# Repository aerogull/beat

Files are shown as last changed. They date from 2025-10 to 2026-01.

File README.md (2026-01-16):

# beat - a mouse designed for any case
I've wanted to design my own mouse for the longest time. I've built my own keyboard, so it was just the next logical step, right? Well, the complexity from a keyboard run off a microcontroller powered by qmk, to a custom programmed mouse with a proprietary mouse sensor and a nRF52 chip, was quite the leap. This is a v1, it's not going to be light, it's not going to be very small, the side button connectors will likely be changed, and the case will not be ergonomic in any way that isn't comfortable to me. The firmware will be slower than most modern mice, and I probably won't be able to bring out the full speed of the PAW3395 sensor used (if I use ESB). But this is a testing board, and changes will be made to improve it in the future! With that, onto the specs and design!
## PCB
- nRF52840
- PAW3395
- 11mm compatible Alps scroll (w middle click)
- 4 Omron Switches (1 other switch for middle click)
- Lipo battery (500mAH)
- Dongle (nRF52840 + USBC) (COMING SOON)
- USBC charging

pcb
schematic1
schematic2
## Case
It's just a simple design without great ergonomics, mostly used for testing and ease of access to the board.
## Firmware
_**Warning: The PAW3395 Driver is Propiretiary, and Can Not Be Provided by Me**_ 

## BOM
|Reference|Qty|Value|DNP|Exclude from BOM|Exclude from Board|Footprint|Datasheet|
|-----|-----|-----|-----|-----|-----|-----|-----|
|A1|1|~||||custom:PAW3395||
|C1,C29,C39|	3|	4.7μF|	|	|	|	Capacitor_SMD:C_0805_2012Metric_Pad1.18x1.45mm_HandSolder|	~|
|C2,C4,C5,C13,C14,C19,C20,C21,C22,C23,C28,C31,C38|	13|	100nF|	|	|	|	Capacitor_SMD:C_0805_2012Metric_Pad1.18x1.45mm_HandSolder|	~|
|C3,C6,C8,C10,C12,C15,C16,C18,C41,C43|	10|	10μF|	|	|	|	Capacitor_SMD:C_0805_2012Metric_Pad1.18x1.45mm_HandSolder|	~|
|C7|	1|	33uF|	|	|	|	Capacitor_SMD:C_0805_2012Metric_Pad1.18x1.45mm_HandSolder|	~|
|C11,C17,C42|	3|	1μF|	|	|	|	Capacitor_SMD:C_0805_2012Metric_Pad1.18x1.45mm_HandSolder|	~|
|C24,C25,C26,C27|	4|	12pF|	|	|	|	Capacitor_SMD:C_0805_2012Metric_Pad1.18x1.45mm_HandSolder|	~|
|C30,C32|	2|	1.0μF|	|	|	|	Capacitor_SMD:C_0805_2012Metric_Pad1.18x1.45mm_HandSolder|	~|
|C33,C37|	2|	N.C.|	|	|	|	Capacitor_SMD:C_0805_2012Metric_Pad1.18x1.45mm_HandSolder|	~|
|C34|	1|	100pF|	|	|	|	Capacitor_SMD:C_0805_2012Metric_Pad1.18x1.45mm_HandSolder|	~|
|C35|	1|	0.8pF|	|	|	|	Capacitor_SMD:C_0805_2012Metric_Pad1.18x1.45mm_HandSolder|	~|
|C36|	1|	0.5pF|	|	|	|	Capacitor_SMD:C_0805_2012Metric_Pad1.18x1.45mm_HandSolder|	~|
|D3,D5|	2|	MBR1020VL|	|	|	|	Diode_SMD:D_SOD-123F|	https://www.onsemi.com/pub/Collateral/MBR1020VL-D.PDF|
|J2|	1|	JSTPH|	|	|	|	custom:JSTPH2PINSMTRIGHTANGLECONNECTOR|	~|
|J3|	1|	USB_C_Receptacle_USB2.0_14P|	|	|	|	Connector_USB:USB_C_Receptacle_Amphenol_12401548E4-2A|	https://www.usb.org/sites/default/files/documents/usb_type-c.zip|
|L1,L4|	2|	10μH|	|	|	|	Inductor_SMD:L_0805_2012Metric_Pad1.05x1.20mm_HandSolder|	~|
|L2|	1|	15nH|	|	|	|	Inductor_SMD:L_0805_2012Metric_Pad1.05x1.20mm_HandSolder|	~|
|L3|	1|	3.3nH|	|	|	|	Inductor_SMD:L_0805_2012Metric_Pad1.05x1.20mm_HandSolder|	~|
|LED1|	1|	SK6812MINI-E|	|	|	|	custom:SK6812MINIE|	http://yushakobo.jp/ds/YS-SK6812MINI-E.pdf|
|R1,R9,R10,R11,R12,R13,R20,R21|	8|	10kΩ|	|	|	|	Resistor_SMD:R_0805_2012Metric_Pad1.20x1.40mm_HandSolder|	~|
|R2|	1|	5.6Ω|	|	|	|	Resistor_SMD:R_0805_2012Metric_Pad1.20x1.40mm_HandSolder|	~|
|R3|	1|	2kΩ|	|	|	|	Resistor_SMD:R_0805_2012Metric_Pad1.20x1.40mm_HandSolder|	~|
|R4,R5,R8|	3|	100kΩ|	|	|	|	Resistor_SMD:R_0805_2012Metric_Pad1.20x1.40mm_HandSolder|	~|
|R6|	1|	5.1kΩ|	|	|	|	Resistor_SMD:R_0805_2012Metric_Pad1.20x1.40mm_HandSolder|	~|
|SW1,SW2,SW4,SW5|	4|	SW_SPST|	|	|	|	custom:SW_Tactile_SPDT_Omron_D2F|	~|
|SW3|	1|	SW_SPST|	|	|	|	Button_Switch_THT:SW_PUSH_6mm|	~|
|SW6,SW7|	2|	SW_SPST|	|	|	|	Capacitor_SMD:C_0402_1005Metric|	~|
|SW8|	1|	RotaryEncoder|	|	|	|	custom:EC10E1220503|	~|
|SW9|	1|	SW_SPST|	|	|	|	Button_Switch_SMD:SW_SPST_CK_RS282G05A3|	~|
|U2|	1|	SPX3819M5-L-3-3|	|	|	|	Package_TO_SOT_SMD:SOT-23-5|	https://www.exar.com/content/document.ashx?id=22106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|
|U3|	1|	MCP73831-2-OT|	|	|	|	Package_TO_SOT_SMD:SOT-23-5|	http://ww1.microchip.com/downloads/en/DeviceDoc/20001984g.pdf|
|U4|	1|	TLV70019_SOT23-5|	|	|	|	Package_TO_SOT_SMD:SOT-23-5|	http://www.ti.com/lit/ds/symlink/tlv700.pdf|
|U5|	1|	nRF52840|	|	|	|	Package_DFN_QFN:Nordic_AQFN-73-1EP_7x7mm_P0.5mm|	http://infocenter.nordicsemi.com/topic/com.nordic.infocenter.nrf52/dita/nrf52/chips/nrf52840.html|
|U6|	1|	SPX3819M5-L-5-0|	|	|	|	Package_TO_SOT_SMD:SOT-23-5|	https://www.exar.com/content/document.ashx?id=22106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|
|Y1|	1|	32.768 Hz|	|	|	|	custom:FC135327680KAA|	~|
|Y2|	1|	32 Hz|	|	|	|	custom:ABM8A32000MHZD2YT3|	~|

part sources for my use:

https://www.aliexpress.us/item/3256808047644394.html\
https://www.aliexpress.us/item/2251832785225269.html\
https://www.aliexpress.us/item/3256808439402083.html\
https://www.aliexpress.us/item/3256808650485013.html\
https://www.aliexpress.us/item/3256808865384672.html\
https://www.aliexpress.us/item/3256809185954100.html

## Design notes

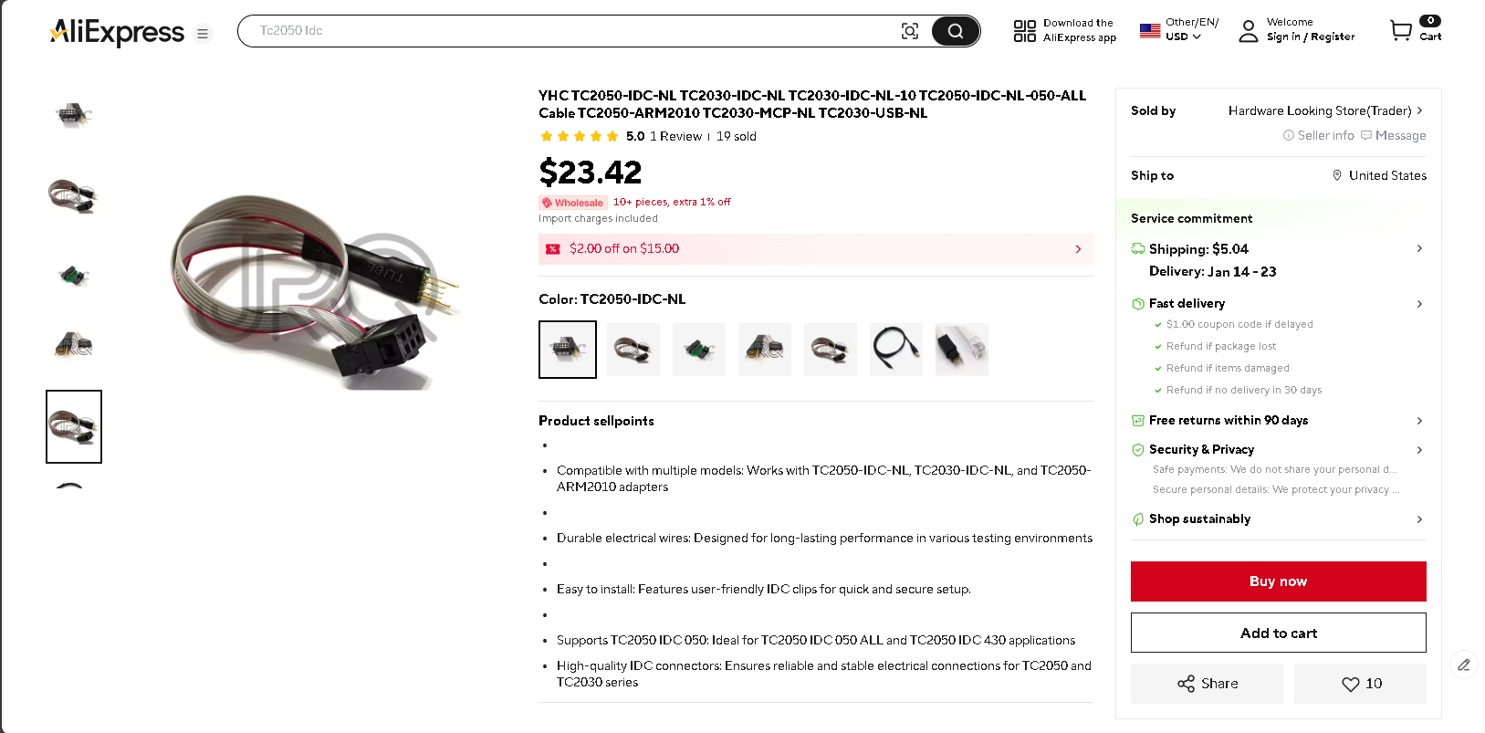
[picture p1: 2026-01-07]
image.png

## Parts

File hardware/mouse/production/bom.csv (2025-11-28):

Designator | Footprint | Quantity | Value | LCSC Part #
A1 | PAW3395 | 1 | ~
C1 | 0805 | 1 | 4.7uF
C10, C12, C15, C16, C18, C3, C40, C41, C43, C6, C8, C9 | 0805 | 12 | 10uF
C11, C17, C42 | 0805 | 3 | 1uF
C13, C14, C19, C2, C20, C21, C22, C23, C28, C31, C38, C4, C5 | 0805 | 13 | 100nF
C24, C25, C26, C27 | 0805 | 4 | 12pF
C29, C39 | 0805 | 2 | 4.7μF
C30, C32 | 0805 | 2 | 1.0μF
C34 | 0805 | 1 | 100pF
C35 | 0805 | 1 | 0.8pF
C36 | 0805 | 1 | 0.5pF
C7 | 0805 | 1 | 33uF
D1, D2, D3, D4, D5, D6 | D_SOD-123F | 6 | MBR1020VL
J2 | JSTPH2PINSMTRIGHTANGLECONNECTOR | 1 | JSTPH
J3 | USB_C_Receptacle_Amphenol_12401548E4-2A | 1 | USB_C_Receptacle_USB2.0_14P
L1, L4 | 0805 | 2 | 10μH
L2 | 0805 | 1 | 15nH
L3 | 0805 | 1 | 3.3nH
LED1 | SK6812MINIE | 1 | SK6812MINI-E
R1, R10, R11, R12, R13, R20, R21, R9 | 0805 | 8 | 10kΩ
R2 | 0805 | 1 | 5.6Ω
R3 | 0805 | 1 | 2kΩ
R4, R5, R8 | 0805 | 3 | 100kΩ
R6 | 0805 | 1 | 5.1kΩ
SW1, SW2, SW4, SW5 | SW_Tactile_SPDT_Omron_D2F | 4 | SW_SPST
SW3 | SW_PUSH_6mm | 1 | SW_SPST
SW6, SW7 | 0402 | 2 | SW_SPST
SW8 | EC10E1220503 | 1 | RotaryEncoder
SW9 | SW_SPST_CK_RS282G05A3 | 1 | SW_SPST
U2 | SOT-23-5 | 1 | SPX3819M5-L-3-3
U3 | SOT-23-5 | 1 | MCP73831-2-OT
U4 | SOT-23-5 | 1 | TLV70019_SOT23-5
U5 | Nordic_AQFN-73-1EP_7x7mm_P0.5mm | 1 | nRF52840
U6 | SOT-23-5 | 1 | SPX3819M5-L-5-0
Y1 | FC135327680KAA | 1 | 32.768 Hz
Y2 | ABM8A32000MHZD2YT3 | 1 | 32 Hz

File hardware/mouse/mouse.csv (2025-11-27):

Id | Designator | Footprint | Quantity | Designation | Supplier and ref
1 | C39,C29 | C_0805_2012Metric_Pad1.18x1.45mm_HandSolder | 2 | 4.7μF
2 | SW3 | SW_PUSH_6mm | 1 | SW_SPST
3 | C30,C32 | C_0805_2012Metric_Pad1.18x1.45mm_HandSolder | 2 | 1.0μF
4 | R21,R20,R10,R11,R1,R9,R12,R13 | R_0805_2012Metric_Pad1.20x1.40mm_HandSolder | 8 | 10kΩ
5 | SW4,SW2,SW1,SW5 | SW_Tactile_SPDT_Omron_D2F | 4 | SW_SPST
6 | C18,C8,C43,C12,C3,C6,C41,C9,C16,C40,C10,C15 | C_0805_2012Metric_Pad1.18x1.45mm_HandSolder | 12 | 10uF
7 | L1,L4 | L_0805_2012Metric_Pad1.05x1.20mm_HandSolder | 2 | 10μH
8 | L3 | L_0805_2012Metric_Pad1.05x1.20mm_HandSolder | 1 | 3.3nH
9 | C37,C33 | C_0805_2012Metric_Pad1.18x1.45mm_HandSolder | 2 | N.C.
10 | J2 | JSTPH2PINSMTRIGHTANGLECONNECTOR | 1 | JSTPH
11 | U3 | SOT-23-5 | 1 | MCP73831-2-OT
12 | C38,C13,C14,C28,C22,C4,C31,C2,C5,C23,C19,C20,C21 | C_0805_2012Metric_Pad1.18x1.45mm_HandSolder | 13 | 100nF
13 | SW6,SW7 | C_0402_1005Metric | 2 | SW_SPST
14 | U5 | Nordic_AQFN-73-1EP_7x7mm_P0.5mm | 1 | nRF52840
15 | A1 | PAW3395 | 1 | ~
16 | Y2 | ABM8A32000MHZD2YT3 | 1 | 32 Hz
17 | Y1 | FC135327680KAA | 1 | 32.768 Hz
18 | SW8 | EC10E1220503 | 1 | RotaryEncoder
19 | C34 | C_0805_2012Metric_Pad1.18x1.45mm_HandSolder | 1 | 100pF
20 | R3 | R_0805_2012Metric_Pad1.20x1.40mm_HandSolder | 1 | 2kΩ
21 | L2 | L_0805_2012Metric_Pad1.05x1.20mm_HandSolder | 1 | 15nH
22 | C35 | C_0805_2012Metric_Pad1.18x1.45mm_HandSolder | 1 | 0.8pF
23 | C36 | C_0805_2012Metric_Pad1.18x1.45mm_HandSolder | 1 | 0.5pF
24 | LED1 | SK6812MINIE | 1 | SK6812MINI-E
25 | SW9 | SW_SPST_CK_RS282G05A3 | 1 | SW_SPST
26 | C17,C11,C42 | C_0805_2012Metric_Pad1.18x1.45mm_HandSolder | 3 | 1uF
27 | D6,D4,D2,D1,D5,D3 | D_SOD-123F | 6 | MBR1020VL
28 | R5,R8,R4 | R_0805_2012Metric_Pad1.20x1.40mm_HandSolder | 3 | 100kΩ
29 | C27,C24,C26,C25 | C_0805_2012Metric_Pad1.18x1.45mm_HandSolder | 4 | 12pF
30 | U2 | SOT-23-5 | 1 | SPX3819M5-L-3-3
31 | R6 | R_0805_2012Metric_Pad1.20x1.40mm_HandSolder | 1 | 5.1kΩ
32 | J3 | USB_C_Receptacle_Amphenol_12401548E4-2A | 1 | USB_C_Receptacle_USB2.0_14P
33 | C1 | C_0805_2012Metric_Pad1.18x1.45mm_HandSolder | 1 | 4.7uF
34 | R2 | R_0805_2012Metric_Pad1.20x1.40mm_HandSolder | 1 | 5.6Ω
35 | U4 | SOT-23-5 | 1 | TLV70019_SOT23-5
36 | U6 | SOT-23-5 | 1 | SPX3819M5-L-5-0
37 | C7 | C_0805_2012Metric_Pad1.18x1.45mm_HandSolder | 1 | 33uF

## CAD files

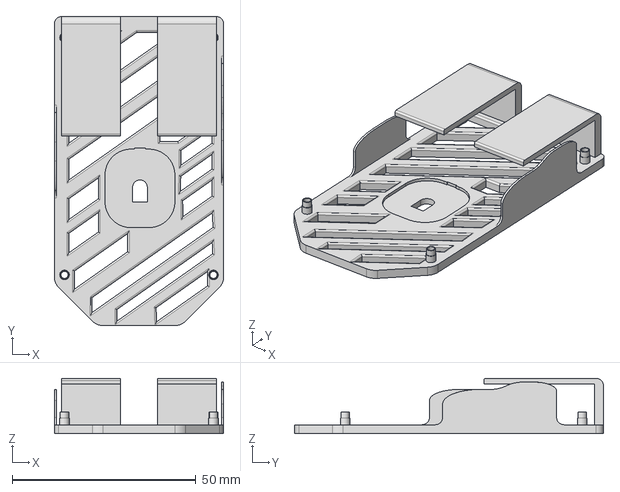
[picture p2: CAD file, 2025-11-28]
case/mouse_case.step
46.0 x 84.0 x 15.0 mm

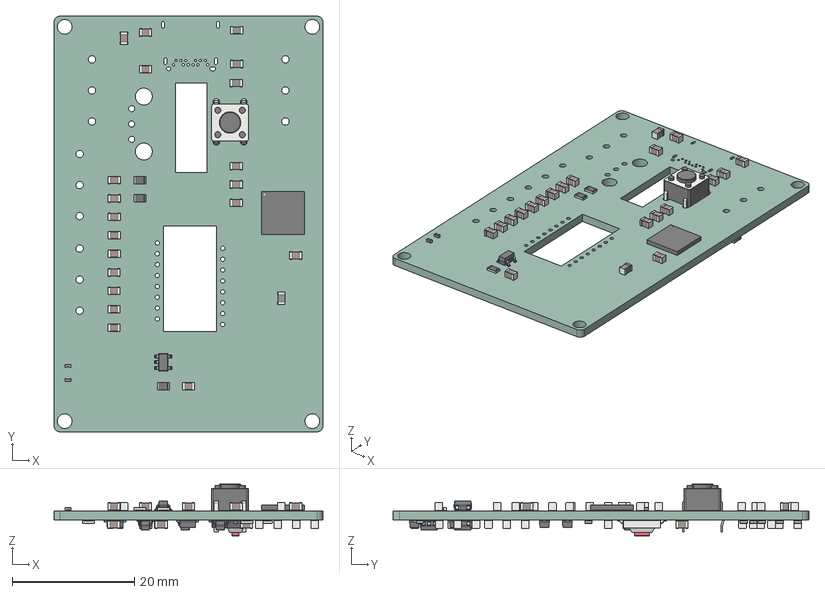
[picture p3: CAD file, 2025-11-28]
hardware/mouse/mouse.step
44.0 x 68.0 x 8.48 mm
C_0805_2012Metric x 43
SW_PUSH_6mm
R_0805_2012Metric x 14
L_0805_2012Metric x 4
SOT-23-5 x 4
C_0402_1005Metric x 2
Nordic_AQFN-73-1EP_7x7mm_P0.5mm
SW_SPST_CK_RS282G05A3
D_SOD-123F x 6
mouse_PCB

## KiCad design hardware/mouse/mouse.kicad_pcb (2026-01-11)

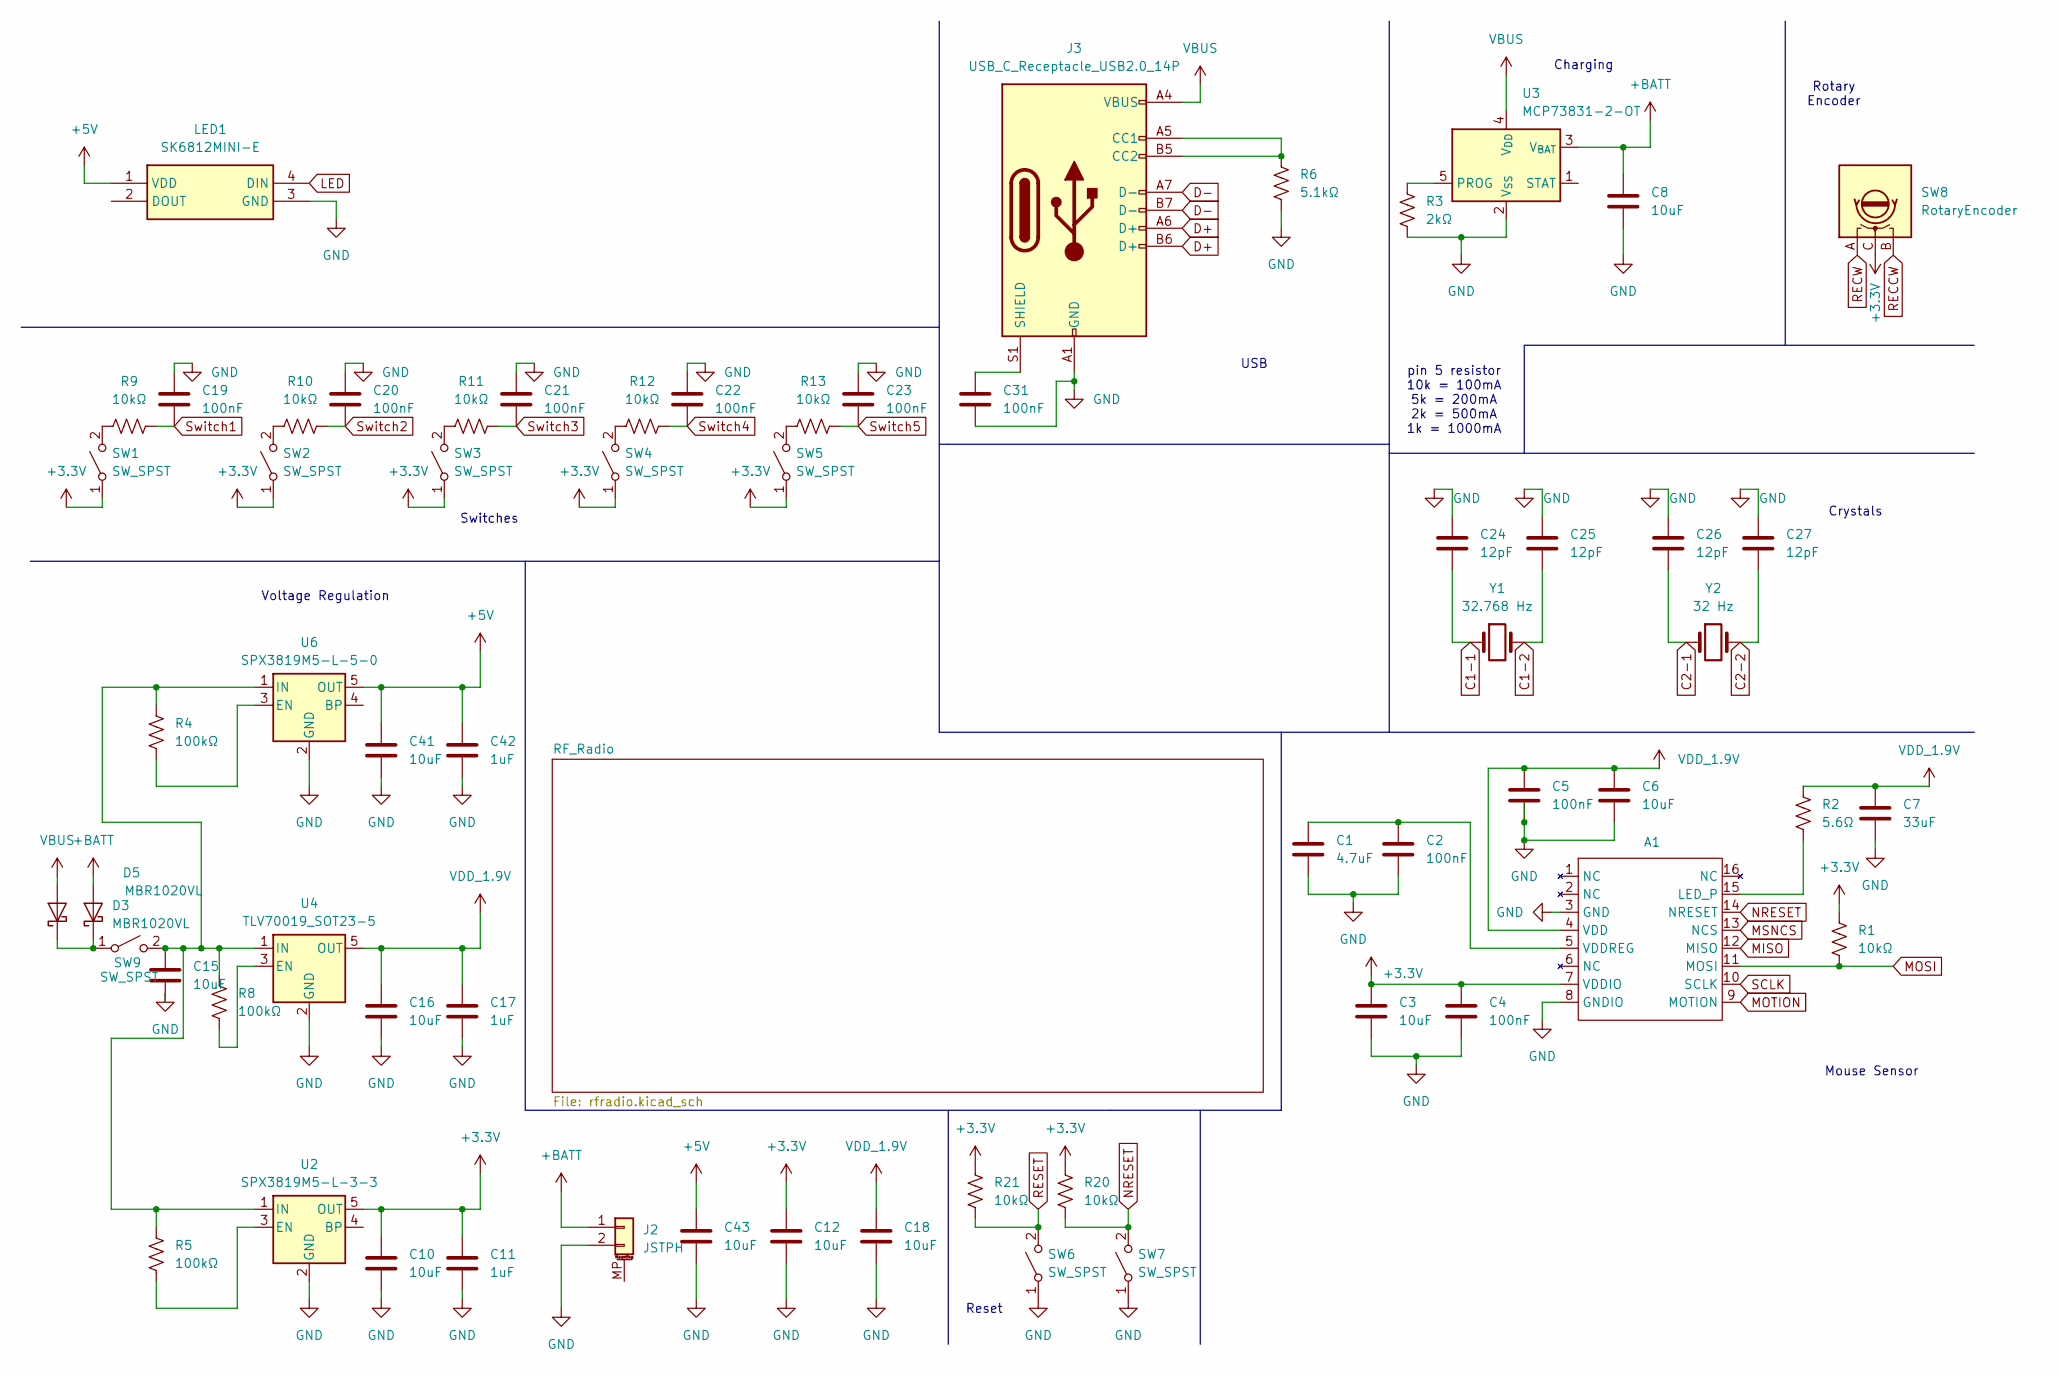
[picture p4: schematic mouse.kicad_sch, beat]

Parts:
A1: PAW3395
C1: 4.7uF; C_0805_2012Metric_Pad1.18x1.45mm_HandSolder
C2, C4, C5, C19, C20, C21, C22, C23, C31: 100nF; C_0805_2012Metric_Pad1.18x1.45mm_HandSolder
C3, C6, C8, C10, C12, C15, C16, C18, C41, C43: 10uF; C_0805_2012Metric_Pad1.18x1.45mm_HandSolder
C7: 33uF; C_0805_2012Metric_Pad1.18x1.45mm_HandSolder
C11, C17, C42: 1uF; C_0805_2012Metric_Pad1.18x1.45mm_HandSolder
C24, C25, C26, C27: 12pF; C_0805_2012Metric_Pad1.18x1.45mm_HandSolder
D3, D5: MBR1020VL; D_SOD-123F
J2: JSTPH; JSTPH2PINSMTRIGHTANGLECONNECTOR
J3: USB_C_Receptacle_USB2.0_14P; USB_C_Receptacle_Amphenol_12401548E4-2A
LED1: SK6812MINI-E; SK6812MINIE; Manufacturer_Part_Number SK6812MINI-E
R1, R9, R10, R11, R12, R13, R20, R21: 10kΩ; R_0805_2012Metric_Pad1.20x1.40mm_HandSolder
R2: 5.6Ω; R_0805_2012Metric_Pad1.20x1.40mm_HandSolder
R3: 2kΩ; R_0805_2012Metric_Pad1.20x1.40mm_HandSolder
R4, R5, R8: 100kΩ; R_0805_2012Metric_Pad1.20x1.40mm_HandSolder
R6: 5.1kΩ; R_0805_2012Metric_Pad1.20x1.40mm_HandSolder
SW1, SW2, SW4, SW5: SW_SPST; SW_Tactile_SPDT_Omron_D2F
SW3: SW_SPST; SW_PUSH_6mm
SW6, SW7: SW_SPST; C_0402_1005Metric
SW8: RotaryEncoder; EC10E1220503
SW9: SW_SPST; SW_SPST_CK_RS282G05A3
U2: SPX3819M5-L-3-3; SOT-23-5
U3: MCP73831-2-OT; SOT-23-5
U4: TLV70019_SOT23-5; SOT-23-5
U6: SPX3819M5-L-5-0; SOT-23-5
Y1: 32.768 Hz; FC135327680KAA
Y2: 32 Hz; ABM8A32000MHZD2YT3

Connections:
+3.3V: A1.7 (VDDIO), C3.1, C4.1, C10.1, C11.1, C12.1, R1.1, R20.2, R21.2, SW1.1 (A), SW2.1 (A), SW3.1 (A), SW4.1 (A), SW5.1 (A), SW8.C, U2.5 (OUT)
+5V: C41.1, C42.1, C43.1, LED1.1 (VDD), U6.5 (OUT)
+BATT: C8.1, D3.2 (A), J2.1, U3.3 (V_{BAT}); also elsewhere on the board
C1-1: C24.2, Y1.1; also elsewhere on the board
C1-2: C25.2, Y1.2; also elsewhere on the board
C2-1: C26.2, Y2.1; also elsewhere on the board
C2-2: C27.2, Y2.2; also elsewhere on the board
D+: J3.A6 (D+), J3.B6 (D+); also elsewhere on the board
D-: J3.A7 (D-), J3.B7 (D-); also elsewhere on the board
GND: A1.3 (GND), A1.8 (GNDIO), C1.2, C2.2, C3.2, C4.2, C5.2, C6.2, C7.2, C8.2, C10.2, C11.2, C12.2, C15.2, C16.2, C17.2, C18.2, C19.1, C20.1, C21.1, C22.1, C23.1, C24.1, C25.1, C26.1, C27.1, C31.2, C41.2, C42.2, C43.2, J2.2, J3.A1 (GND), J3.A12 (GND), J3.B1 (GND), J3.B12 (GND), LED1.3 (GND), R3.1, R6.1, SW6.1 (A), SW7.1 (A), U2.2 (GND), U3.2 (V_{SS}), U4.2 (GND), U6.2 (GND); also elsewhere on the board
LED: LED1.4 (DIN); also elsewhere on the board
MISO: A1.12 (MISO); also elsewhere on the board
MOSI: A1.11 (MOSI), R1.2; also elsewhere on the board
MOTION: A1.9 (MOTION); also elsewhere on the board
MSNCS: A1.13 (NCS); also elsewhere on the board
NRESET: A1.14 (NRESET), R20.1, SW7.2 (B)
unnamed: A1.15 (LED_P), R2.2
unnamed: A1.5 (VDDREG), C1.1, C2.1
unnamed: D3.1 (K), D5.1 (K), SW9.1 (A)
unnamed: J3.A5 (CC1), J3.B5 (CC2), R6.2
unnamed: C31.1, J3.S1 (SHIELD)
unnamed: R9.1, SW1.2 (B)
unnamed: R10.1, SW2.2 (B)
unnamed: R11.1, SW3.2 (B)
unnamed: R12.1, SW4.2 (B)
unnamed: R13.1, SW5.2 (B)
unnamed: C15.1, R4.1, R5.1, R8.1, SW9.2 (B), U2.1 (IN), U4.1 (IN), U6.1 (IN)
unnamed: R5.2, U2.3 (EN)
unnamed: R3.2, U3.5 (PROG)
unnamed: R8.2, U4.3 (EN)
unnamed: R4.2, U6.3 (EN)
RECCW: SW8.B; also elsewhere on the board
RECW: SW8.A; also elsewhere on the board
RESET: R21.1, SW6.2 (B); also elsewhere on the board
SCLK: A1.10 (SCLK); also elsewhere on the board
Switch1: C19.2, R9.2; also elsewhere on the board
Switch2: C20.2, R10.2; also elsewhere on the board
Switch3: C21.2, R11.2; also elsewhere on the board
Switch4: C22.2, R12.2; also elsewhere on the board
Switch5: C23.2, R13.2; also elsewhere on the board
VBUS: D5.2 (A), J3.A4 (VBUS), J3.A9 (VBUS), J3.B4 (VBUS), J3.B9 (VBUS), U3.4 (V_{DD}); also elsewhere on the board
VDD_1.9V: A1.4 (VDD), C5.1, C6.1, C7.1, C16.1, C17.1, C18.1, R2.1, U4.5 (OUT)

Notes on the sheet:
Crystals
Mouse Sensor
Reset
Voltage Regulation
Charging
Switches
USB
Rotary Encoder
pin 5 resistor 10k = 100mA 5k = 200mA 2k = 500mA 1k = 1000mA

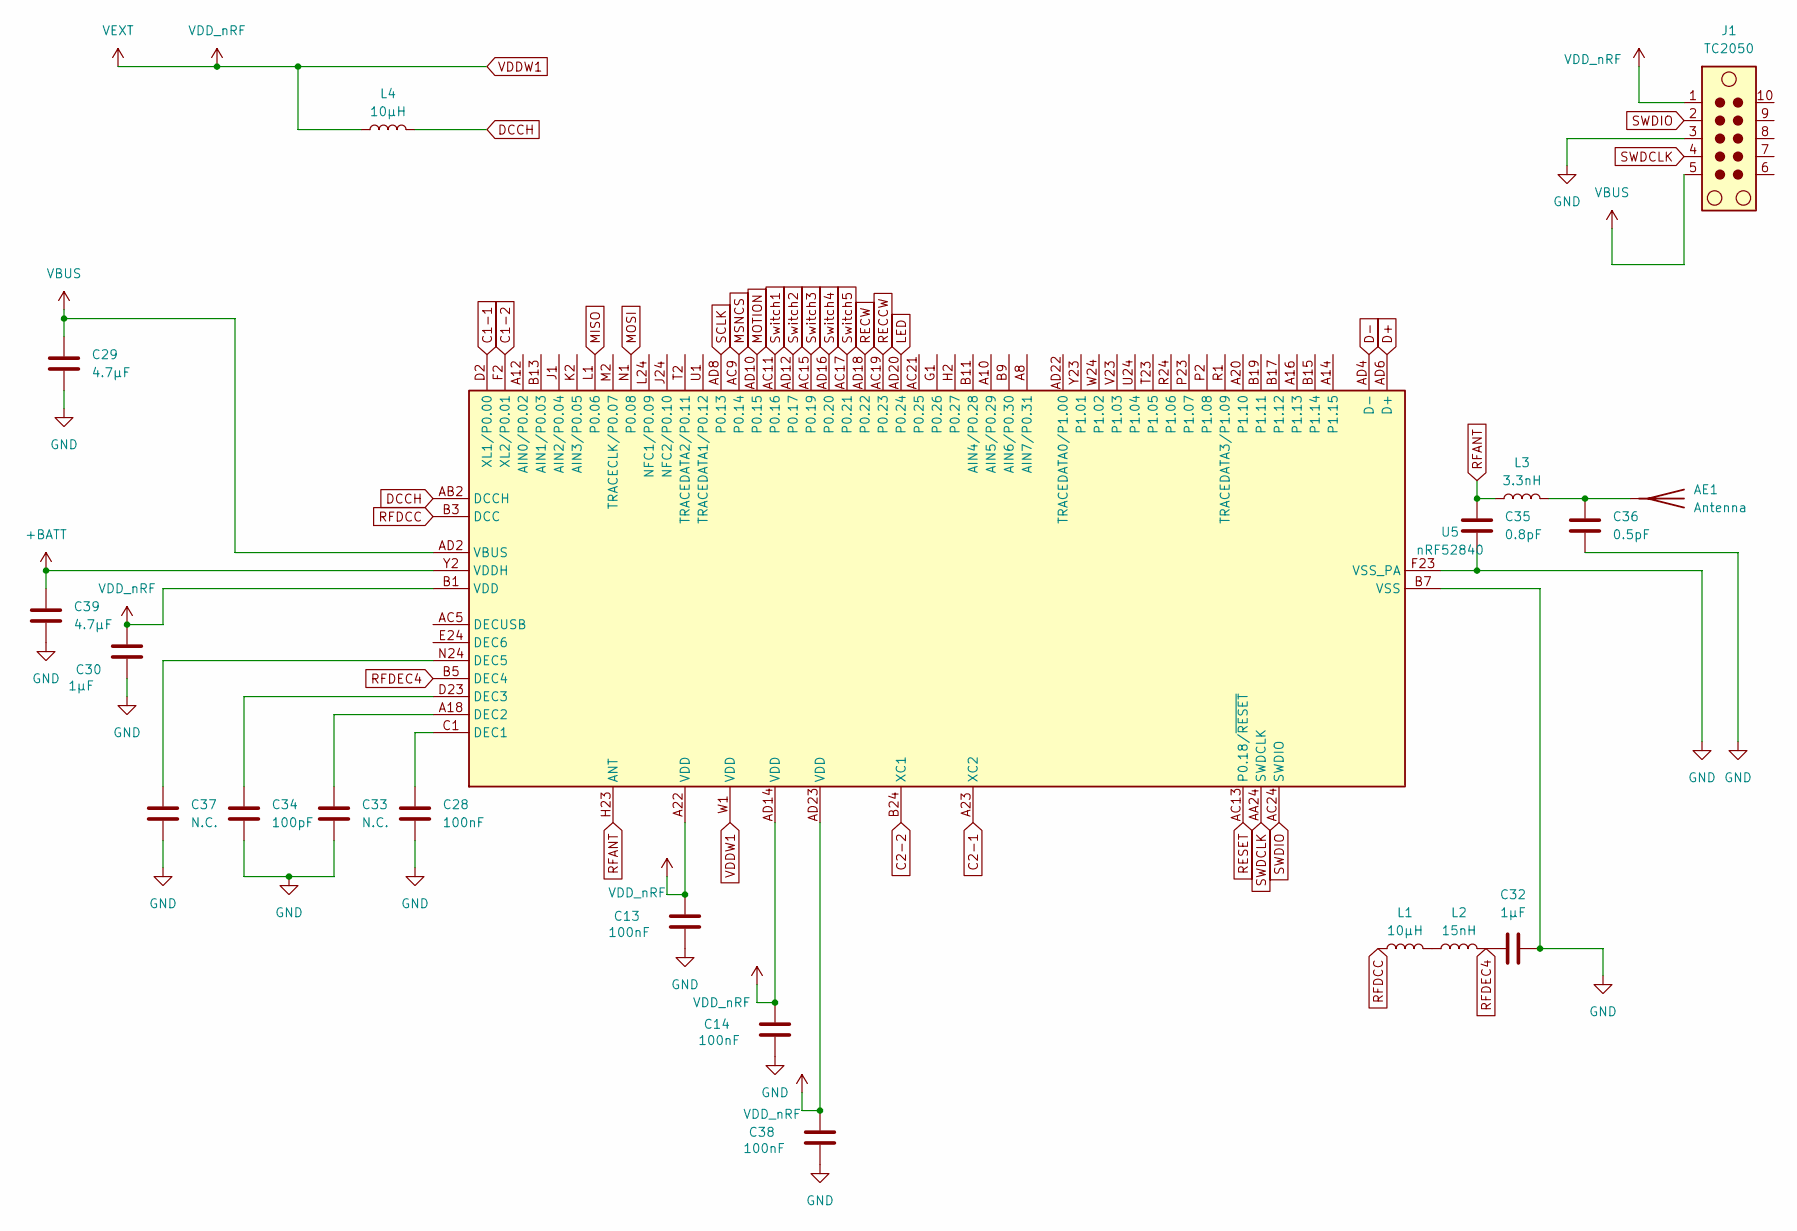
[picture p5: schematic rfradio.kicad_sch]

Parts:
AE1: Antenna; Texas_SWRA117D_2.4GHz_Left
C13, C14, C28, C38: 100nF; C_0805_2012Metric_Pad1.18x1.45mm_HandSolder
C29, C39: 4.7μF; C_0805_2012Metric_Pad1.18x1.45mm_HandSolder
C30, C32: 1μF; C_0805_2012Metric_Pad1.18x1.45mm_HandSolder
C33, C37: N.C.; C_0805_2012Metric_Pad1.18x1.45mm_HandSolder
C34: 100pF; C_0805_2012Metric_Pad1.18x1.45mm_HandSolder
C35: 0.8pF; C_0805_2012Metric_Pad1.18x1.45mm_HandSolder
C36: 0.5pF; C_0805_2012Metric_Pad1.18x1.45mm_HandSolder
J1: TC2050; Tag-Connect_TC2050-IDC-NL_2x05_P1.27mm_Vertical
L1, L4: 10μH; L_0805_2012Metric_Pad1.05x1.20mm_HandSolder
L2: 15nH; L_0805_2012Metric_Pad1.05x1.20mm_HandSolder
L3: 3.3nH; L_0805_2012Metric_Pad1.05x1.20mm_HandSolder
U5: nRF52840; Nordic_AQFN-73-1EP_7x7mm_P0.5mm

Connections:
+BATT: C39.1, U5.Y2 (VDDH); also elsewhere on the board
C1-1: U5.D2 (XL1/P0.00); also elsewhere on the board
C1-2: U5.F2 (XL2/P0.01); also elsewhere on the board
C2-1: U5.A23 (XC2); also elsewhere on the board
C2-2: U5.B24 (XC1); also elsewhere on the board
D+: U5.AD6 (D+); also elsewhere on the board
D-: U5.AD4 (D-); also elsewhere on the board
DCCH: L4.2, U5.AB2 (DCCH)
GND: C13.2, C14.2, C28.2, C29.2, C30.2, C32.2, C33.2, C34.2, C35.2, C36.2, C37.2, C38.2, C39.2, J1.3, U5.B7 (VSS), U5.EP (VSS), U5.F23 (VSS_PA); also elsewhere on the board
LED: U5.AD20 (P0.24); also elsewhere on the board
MISO: U5.L1 (P0.06); also elsewhere on the board
MOSI: U5.N1 (P0.08); also elsewhere on the board
MOTION: U5.AD10 (P0.15); also elsewhere on the board
MSNCS: U5.AC9 (P0.14); also elsewhere on the board
unnamed: AE1.1, C36.1, L3.2
unnamed: L1.2, L2.1
unnamed: C28.1, U5.C1 (DEC1)
unnamed: C33.1, U5.A18 (DEC2)
unnamed: C34.1, U5.D23 (DEC3)
unnamed: C37.1, U5.N24 (DEC5)
RECCW: U5.AC19 (P0.23); also elsewhere on the board
RECW: U5.AD18 (P0.22); also elsewhere on the board
RESET: U5.AC13 (P0.18/~RESET); also elsewhere on the board
RFANT: C35.1, L3.1, U5.H23 (ANT)
RFDCC: L1.1, U5.B3 (DCC)
RFDEC4: C32.1, L2.2, U5.B5 (DEC4)
SCLK: U5.AD8 (P0.13); also elsewhere on the board
SWDCLK: J1.4, U5.AA24 (SWDCLK)
SWDIO: J1.2, U5.AC24 (SWDIO)
Switch1: U5.AC11 (P0.16); also elsewhere on the board
Switch2: U5.AD12 (P0.17); also elsewhere on the board
Switch3: U5.AC15 (P0.19); also elsewhere on the board
Switch4: U5.AD16 (P0.20); also elsewhere on the board
Switch5: U5.AC17 (P0.21); also elsewhere on the board
VBUS: C29.1, J1.5, U5.AD2 (VBUS); also elsewhere on the board
VDDW1: C13.1, C14.1, C30.1, C38.1, J1.1, L4.1, U5.A22 (VDD), U5.AD14 (VDD), U5.AD23 (VDD), U5.B1 (VDD), U5.W1 (VDD)

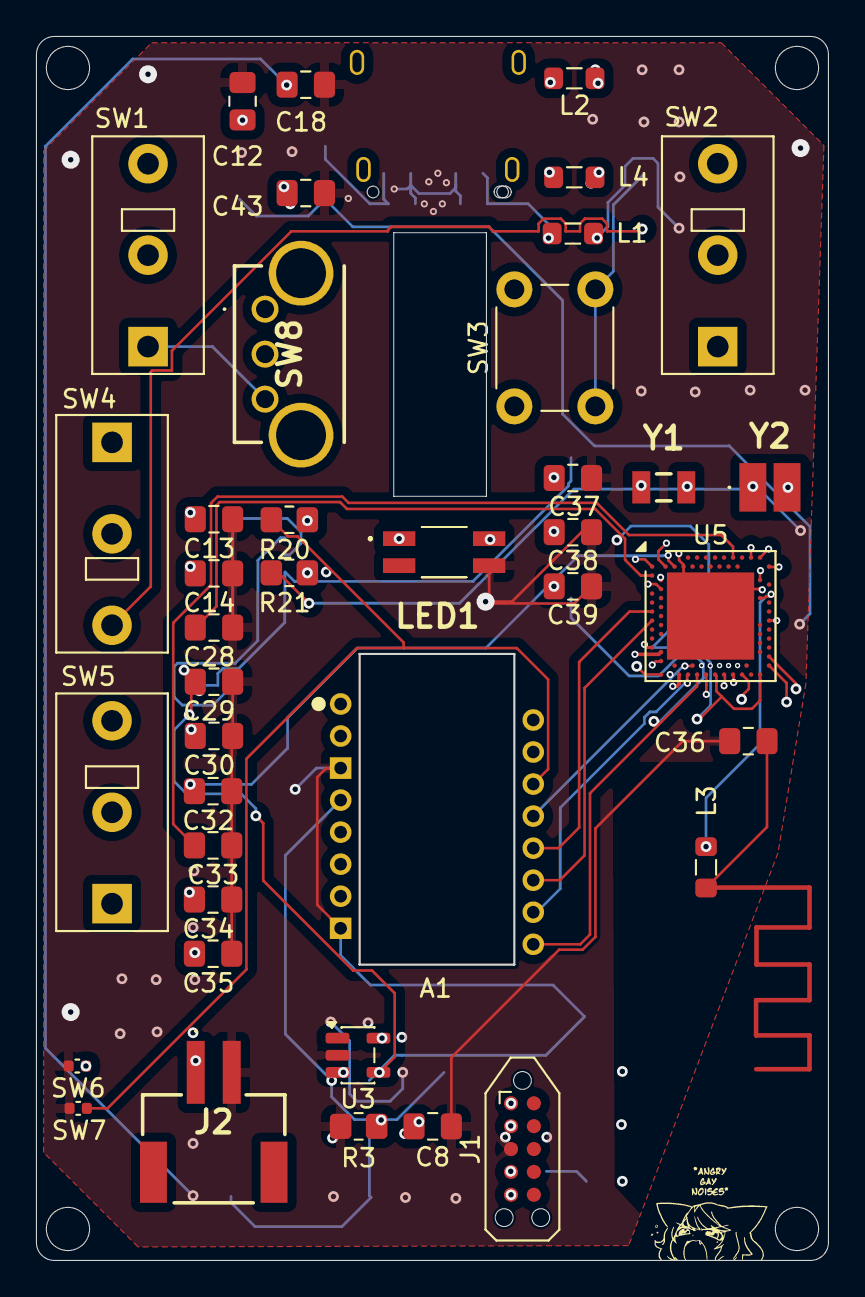
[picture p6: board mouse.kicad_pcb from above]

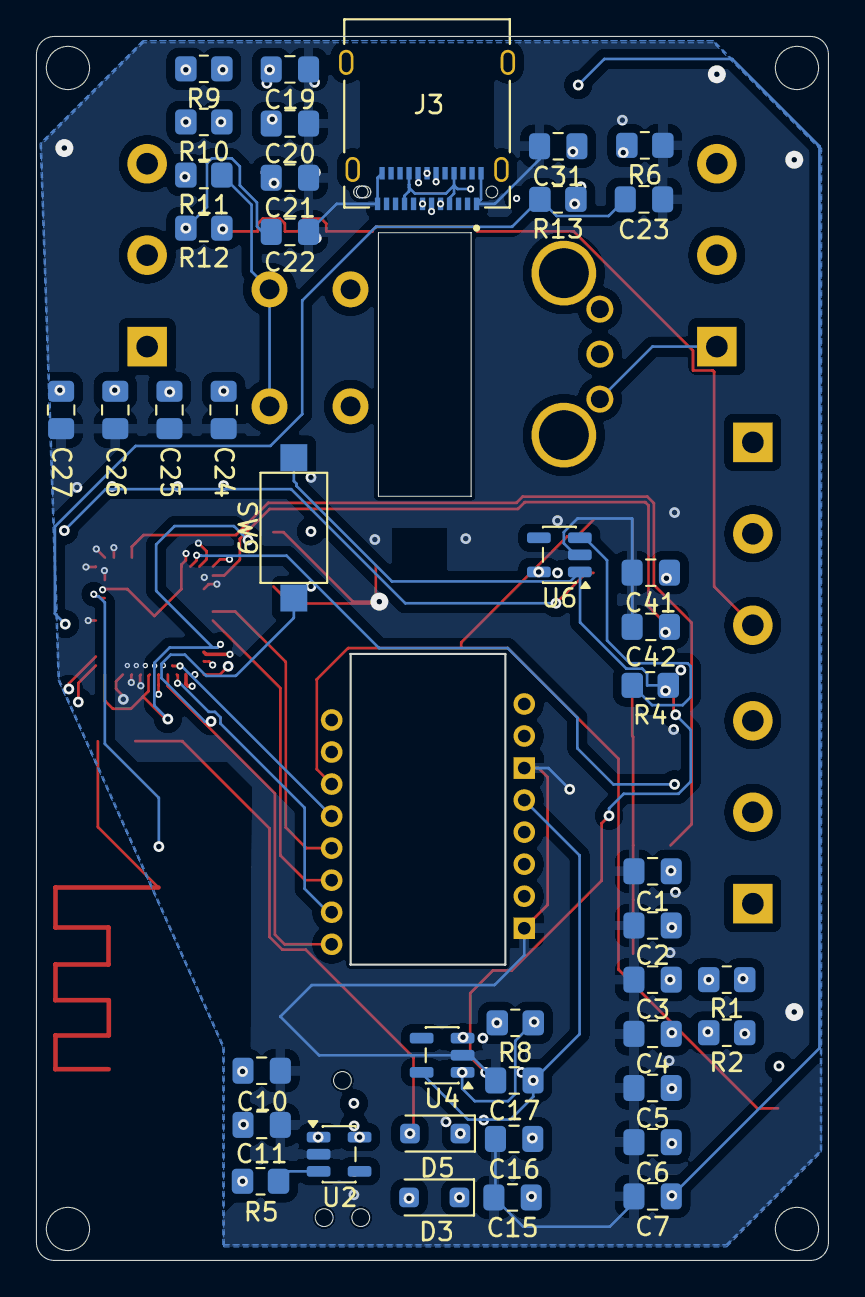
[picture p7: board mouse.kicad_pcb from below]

Board: 6 copper layers, 44.0 x 68.0 mm, 82 parts (42 on the bottom side), 54 nets.

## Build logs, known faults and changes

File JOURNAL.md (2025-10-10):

<!--
  ===================    !!READ THIS NOTICE!!   ====================
  DO NOT edit this file manually. Your changes WILL BE OVERWRITTEN!
  This journal is auto generated and updated by Hack Club Blueprint.
  To edit this file, please edit your journal entries on Blueprint.
  ==================================================================
-->

This is my journal of the design and building process of **beat**.  
You can view this journal in more detail on **Hack Club Blueprint** [here](https://blueprint.hackclub.com/projects/368).

## 10/9/2025 7 PM - started working on the basic devboard  

i worked with the adafruit feather m0 devboard and started customizing it to my spec. figured out some parts i needed and decided not to use the rp2040 for now. i've almost finished making sure everything is correct, and i'll be triple checking everything against the docs soon. i also added the mouse sensors according to the specs provided by pixart.   

## 10/9/2025 8 PM - added 1.9v and switches  

i added the linear voltage regulator and supporting electronics for the 1.9v current required to run the paw3395 sensor. i also started adding the wiring for the mouse switches. they use spst switches from omron. i also added rc filter to each of the switches, using a 1.5kOhm resistor and a 1uF capaciator. also, i sectioned off the schematic.

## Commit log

2025-10-10 added 1.9v supply and 5 switches
    [mouse.kicad_sch]
2025-11-13 finished schem, peer review next
    [mouse.kicad_sch, rfradio.kicad_sch]
2025-11-27 mostly just eod stuff, a couple csv files and readme changes
    [bom.csv, designators.csv, mouse.csv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]
2025-11-28 added case v1
    [bom.csv, designators.csv, mouse.csv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]
2025-12-29 meow :3
    [mouse.kicad_pcb]
2025-12-29 wowsa, thats a lot o' debugging
    [dongle.kicad_pcb, dongle.kicad_sch, mouse.kicad_pcb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]
2026-01-01 trying to understand what jlc is doing
    [designators.csv, dongle.kicad_sch, mouse.kicad_pcb]
2026-01-06 idr what changed in this one
    [mouse.kicad_pcb]
2026-01-11 some changes
    [mouse.kicad_pcb]
